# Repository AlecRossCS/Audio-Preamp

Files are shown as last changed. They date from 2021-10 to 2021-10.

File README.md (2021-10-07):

# Audio-Preamp
This is an analog audio preamplifier, designed on first principles as well as help from Small Signal Audio Design by Douglas Self, as well as applications notes from Rod Elliott. 

## Schematic
the schematic is listed in the project files, in many parts. [the pdf schematic is linked here](Audio_Preamp.pdf)

## Power Supply Design
The design for the power supply relies on an Input AC plug pack, anywhere between 12-25V input.
power supply_schematic
it is designed with some input protection from transient spikes of wall voltage, if the plug pack is poorly designed by a MOV. Effectively it is a half wave rectifier for each rail, and a virtual ground point.  Otherwise it is a fairly standard linear power supply, except that to reduce cost and part count, a input capacitance is obtained through a capacitance multiplier. the only disadvantage is that it cannot help source higher currents, but that is not needed on a preamplifier as well as being mitigated by a high output capacitance. 

## Other Design elements

The rest of the design is fairly lengthy, and involves several larger elements taken from basic principles. The input is a standard RCA audio jack, as it is an easier connection and has better noise characteristics than a balanced input. the controls follow with a baxendall tonal control, and then a baxendall volume control. All of this is designed to be very low noise (-90DB) and high fidelity all analog preamp. 

## Hardware layout

This board needed to be relatively space efficient, and total space is one factor which influences cost of production. so this is designed as a 50x80 mm  4 layer board, which should make a favorable production cost. as this is fiarly small and lower power another cost saver is it only needs 1 oz copper, not 2 oz copper. Another point for production is that almost all components are SMD, thus decreases cost of assembly. 

overall mockup:
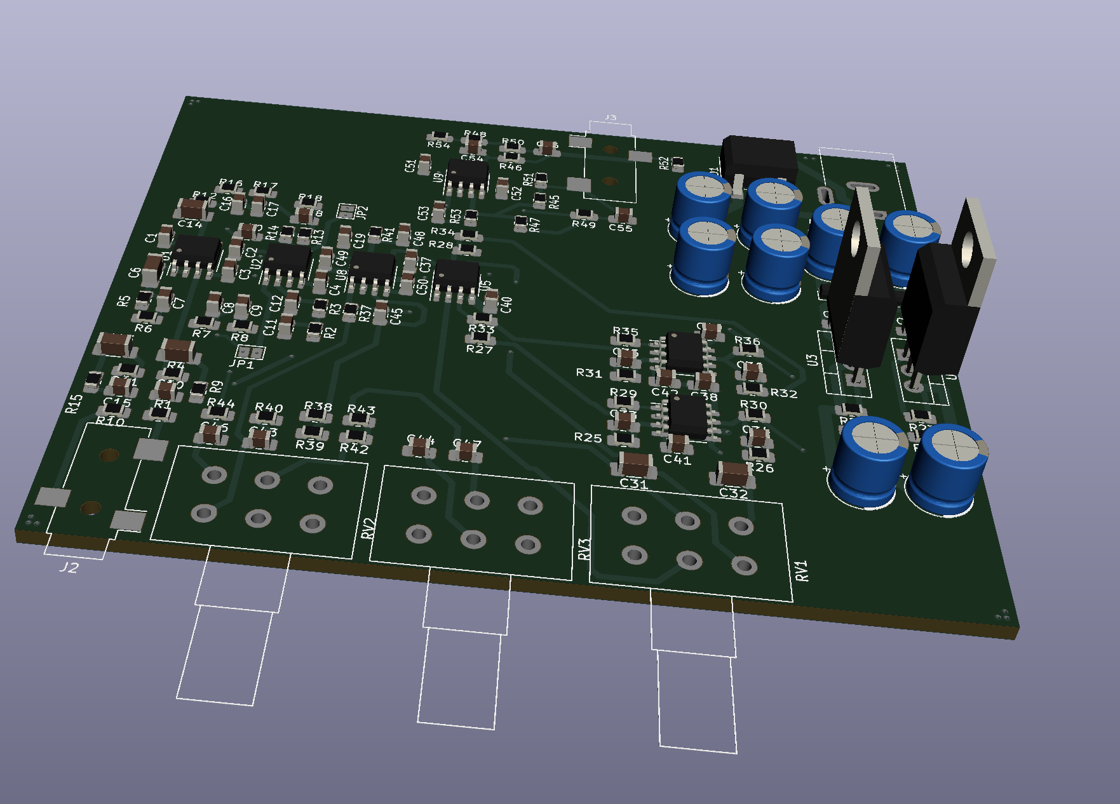
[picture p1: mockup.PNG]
model


## version 2
This version has RCA out, but V2 may have balanced output as well as active crossovers.

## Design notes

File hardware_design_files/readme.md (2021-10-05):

# Hardware Design File Section
all schematics created using Kicad

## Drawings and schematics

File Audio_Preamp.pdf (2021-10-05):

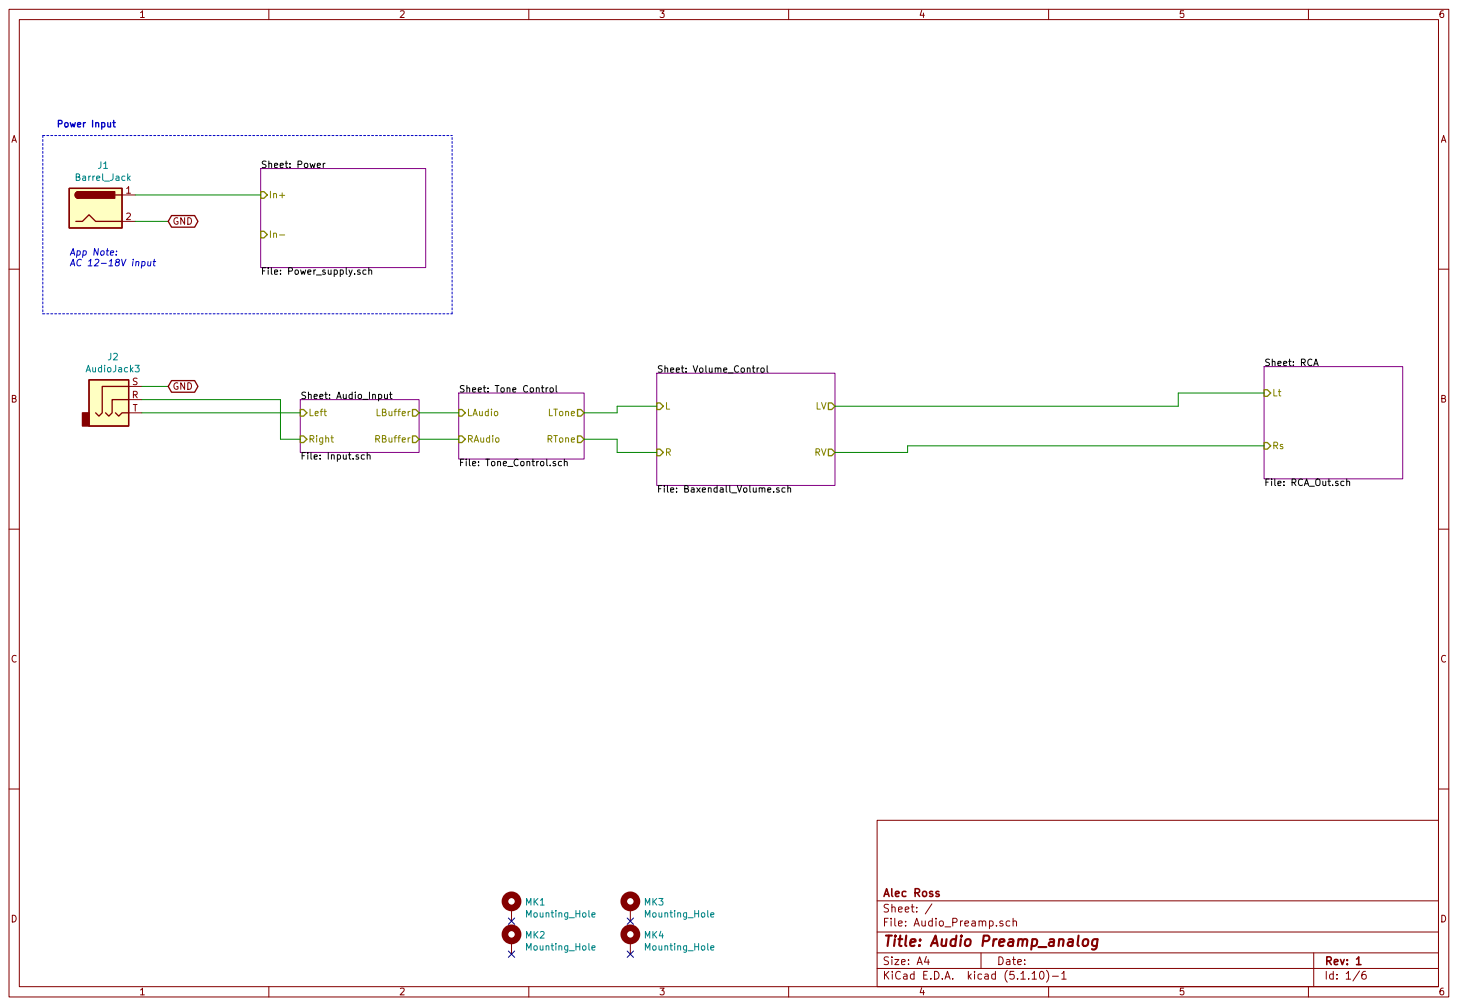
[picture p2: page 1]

Sheet: Power File: Power_supply.sch

Lt Rs Sheet: Tone Control File: Tone_Control.sch

File: Audio_Preamp.sch Sheet: / Alec Ross

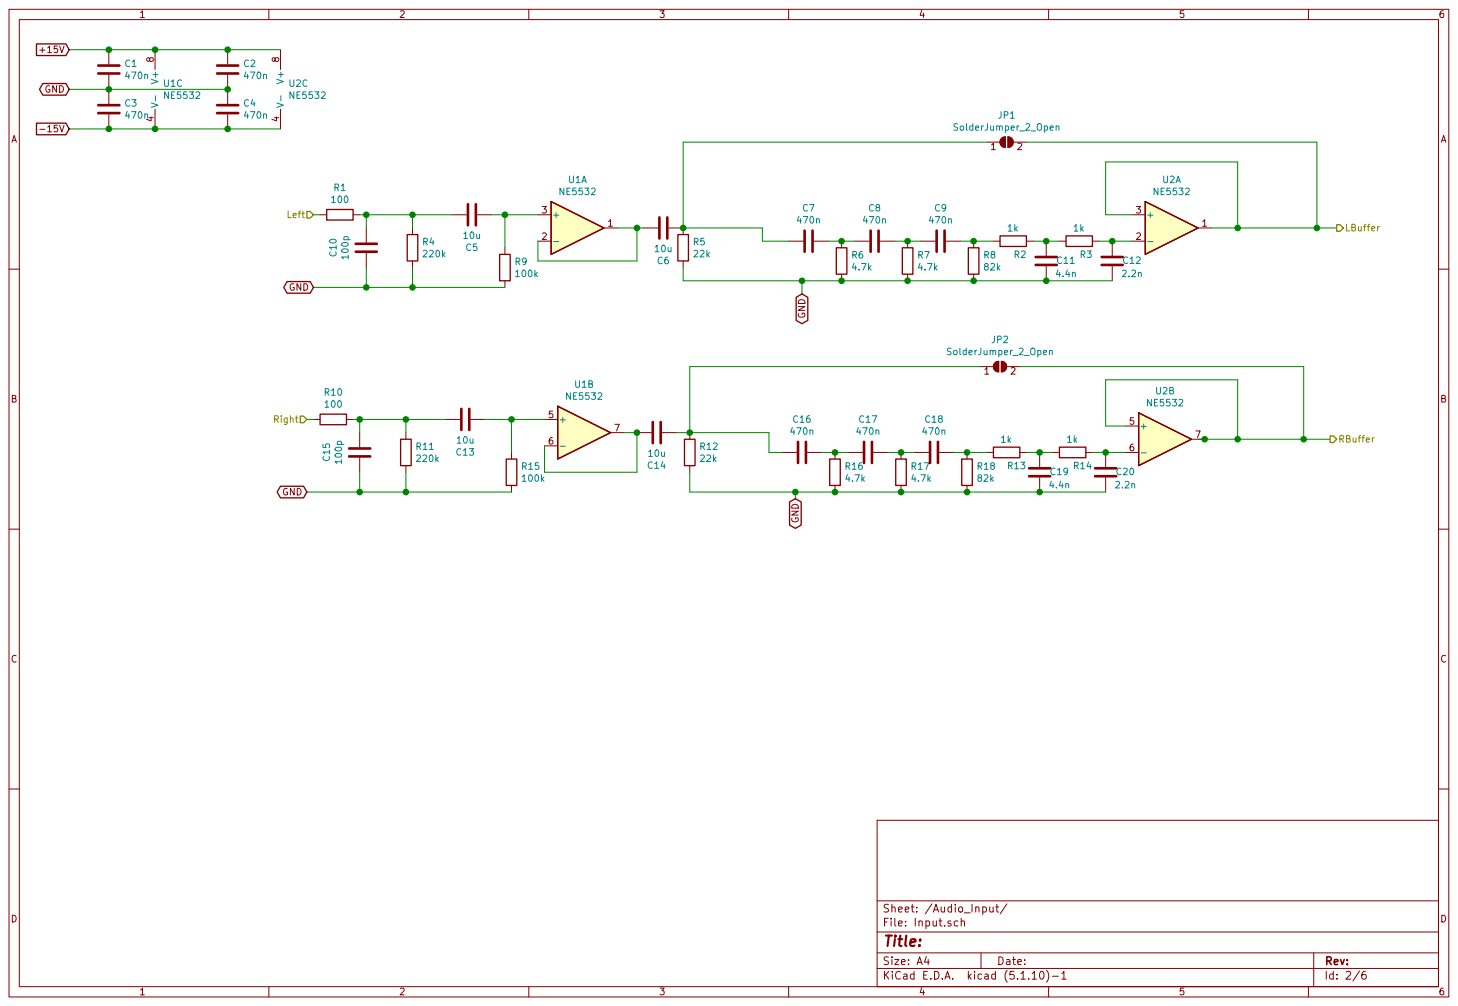
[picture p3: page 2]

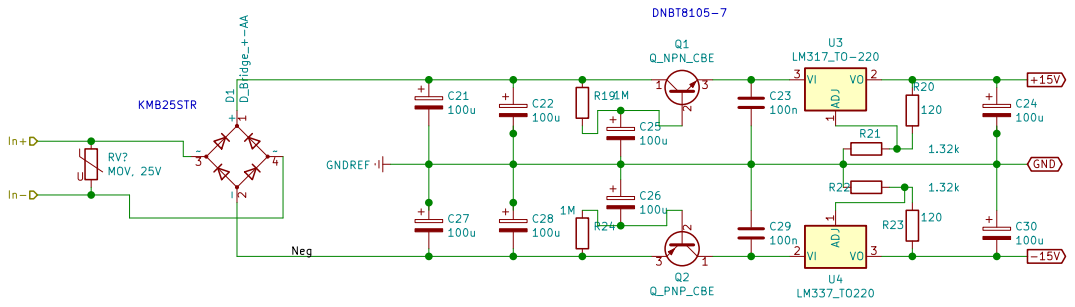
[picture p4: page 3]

File: Power_supply.sch Sheet: /Power/
Id: 3/6 Title:

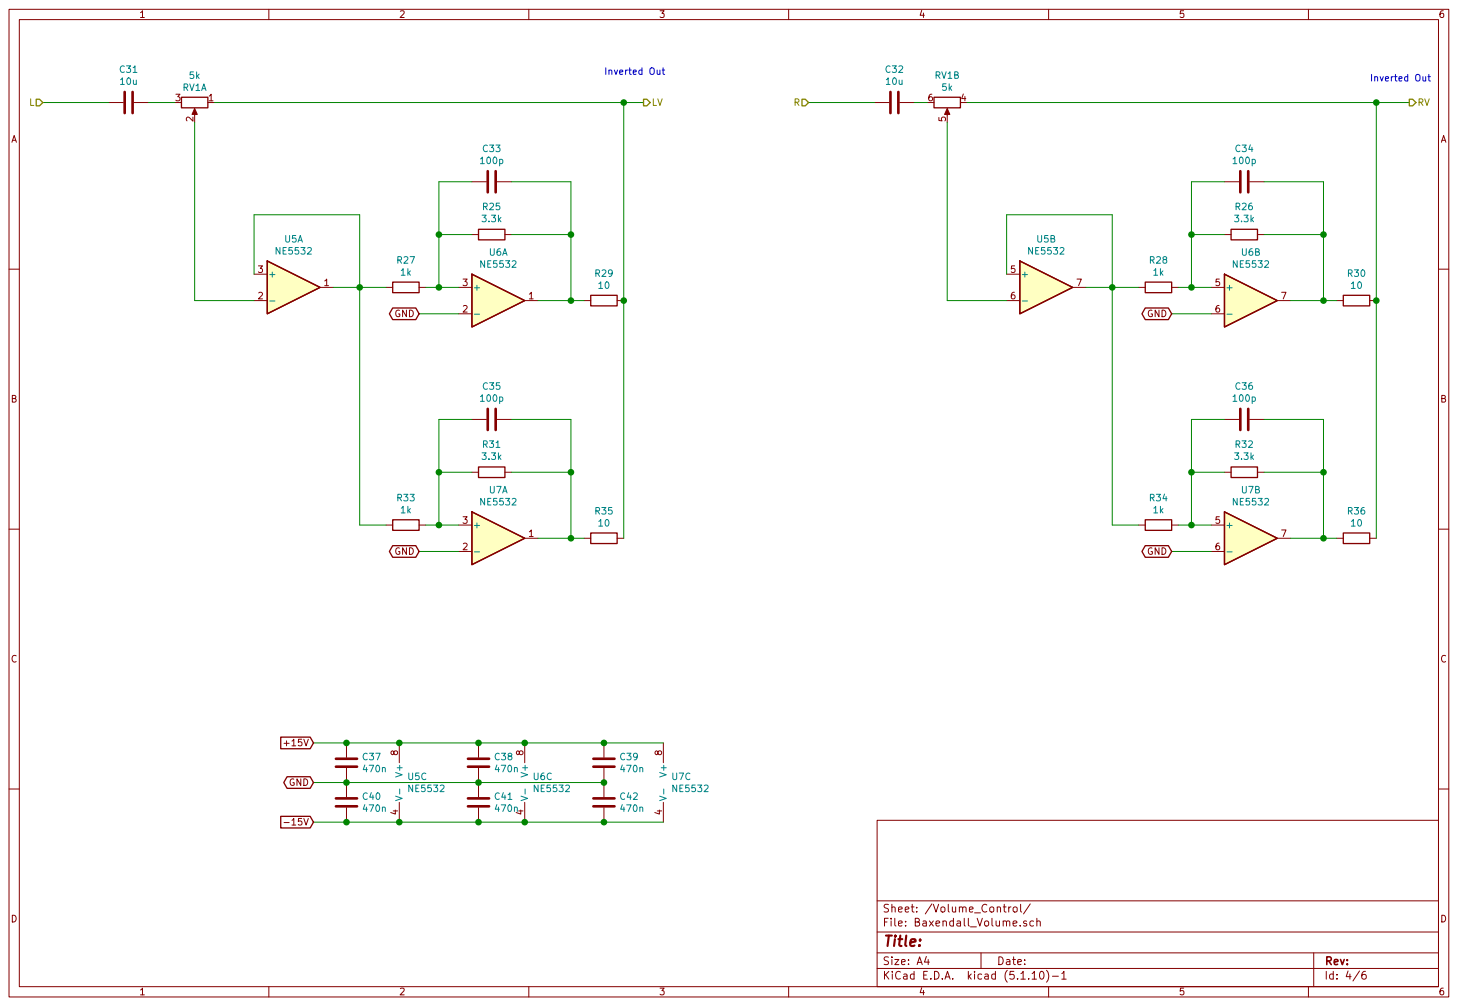
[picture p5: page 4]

Inverted Out

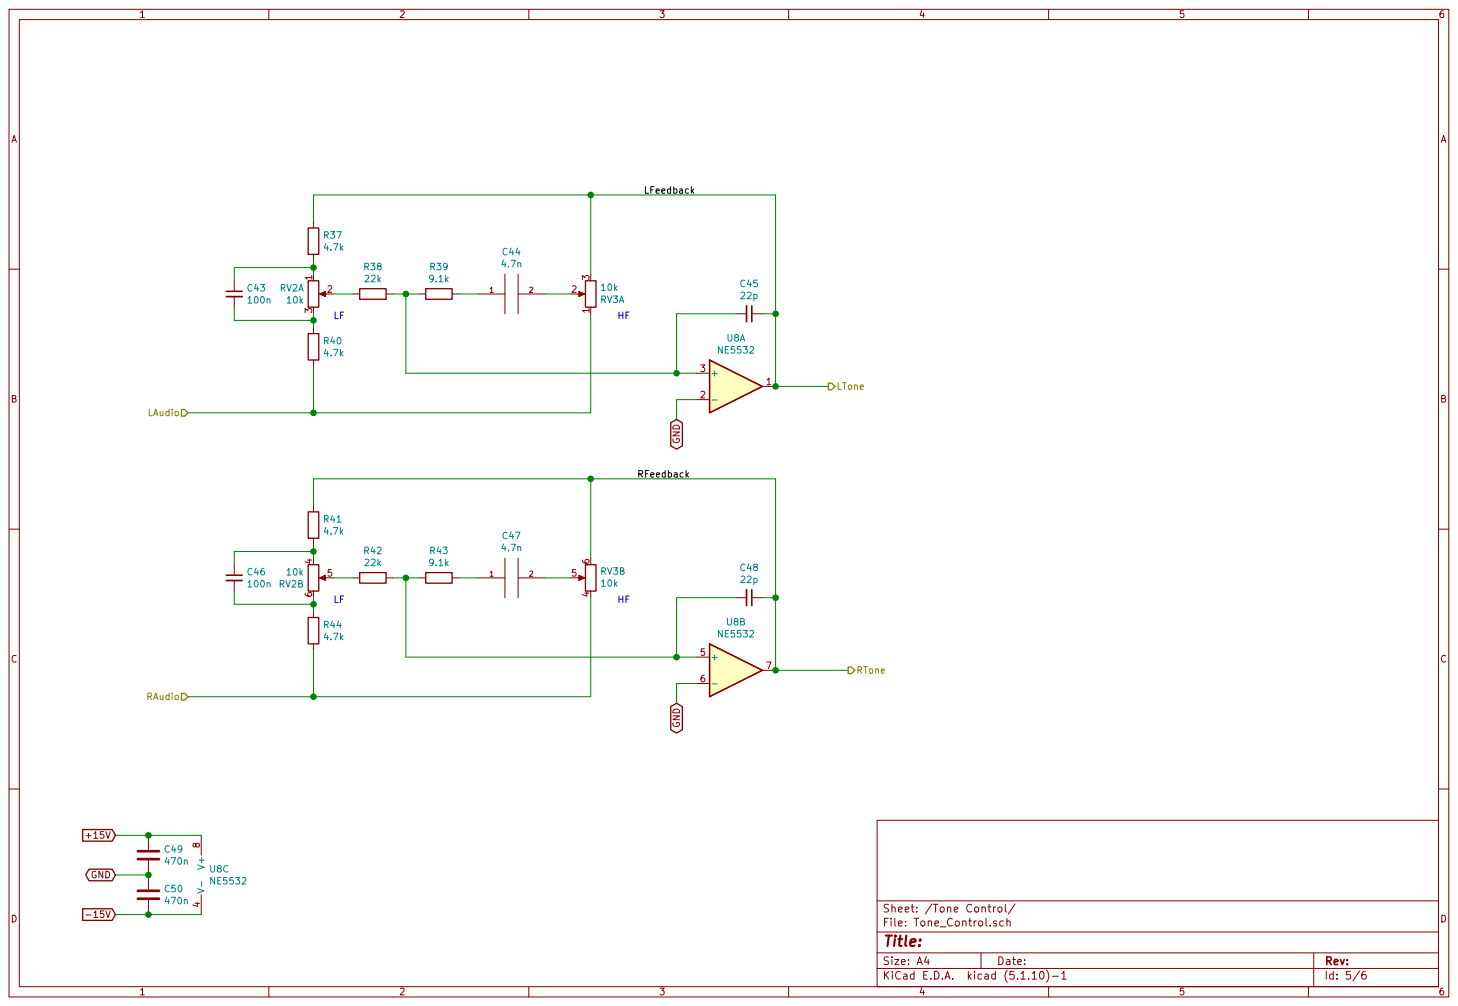
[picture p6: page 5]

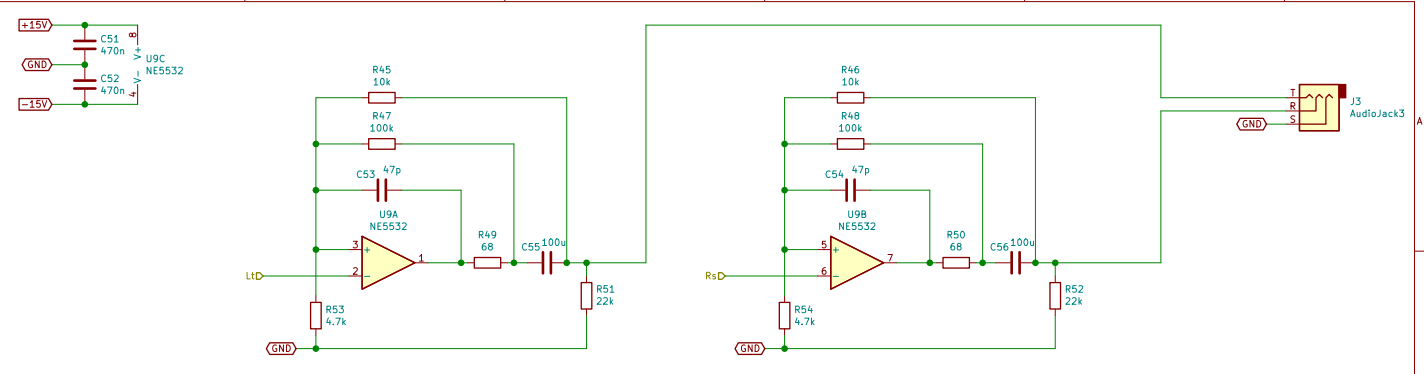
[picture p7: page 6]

File: RCA_Out.sch Sheet: /RCA/
Id: 6/6 Title:

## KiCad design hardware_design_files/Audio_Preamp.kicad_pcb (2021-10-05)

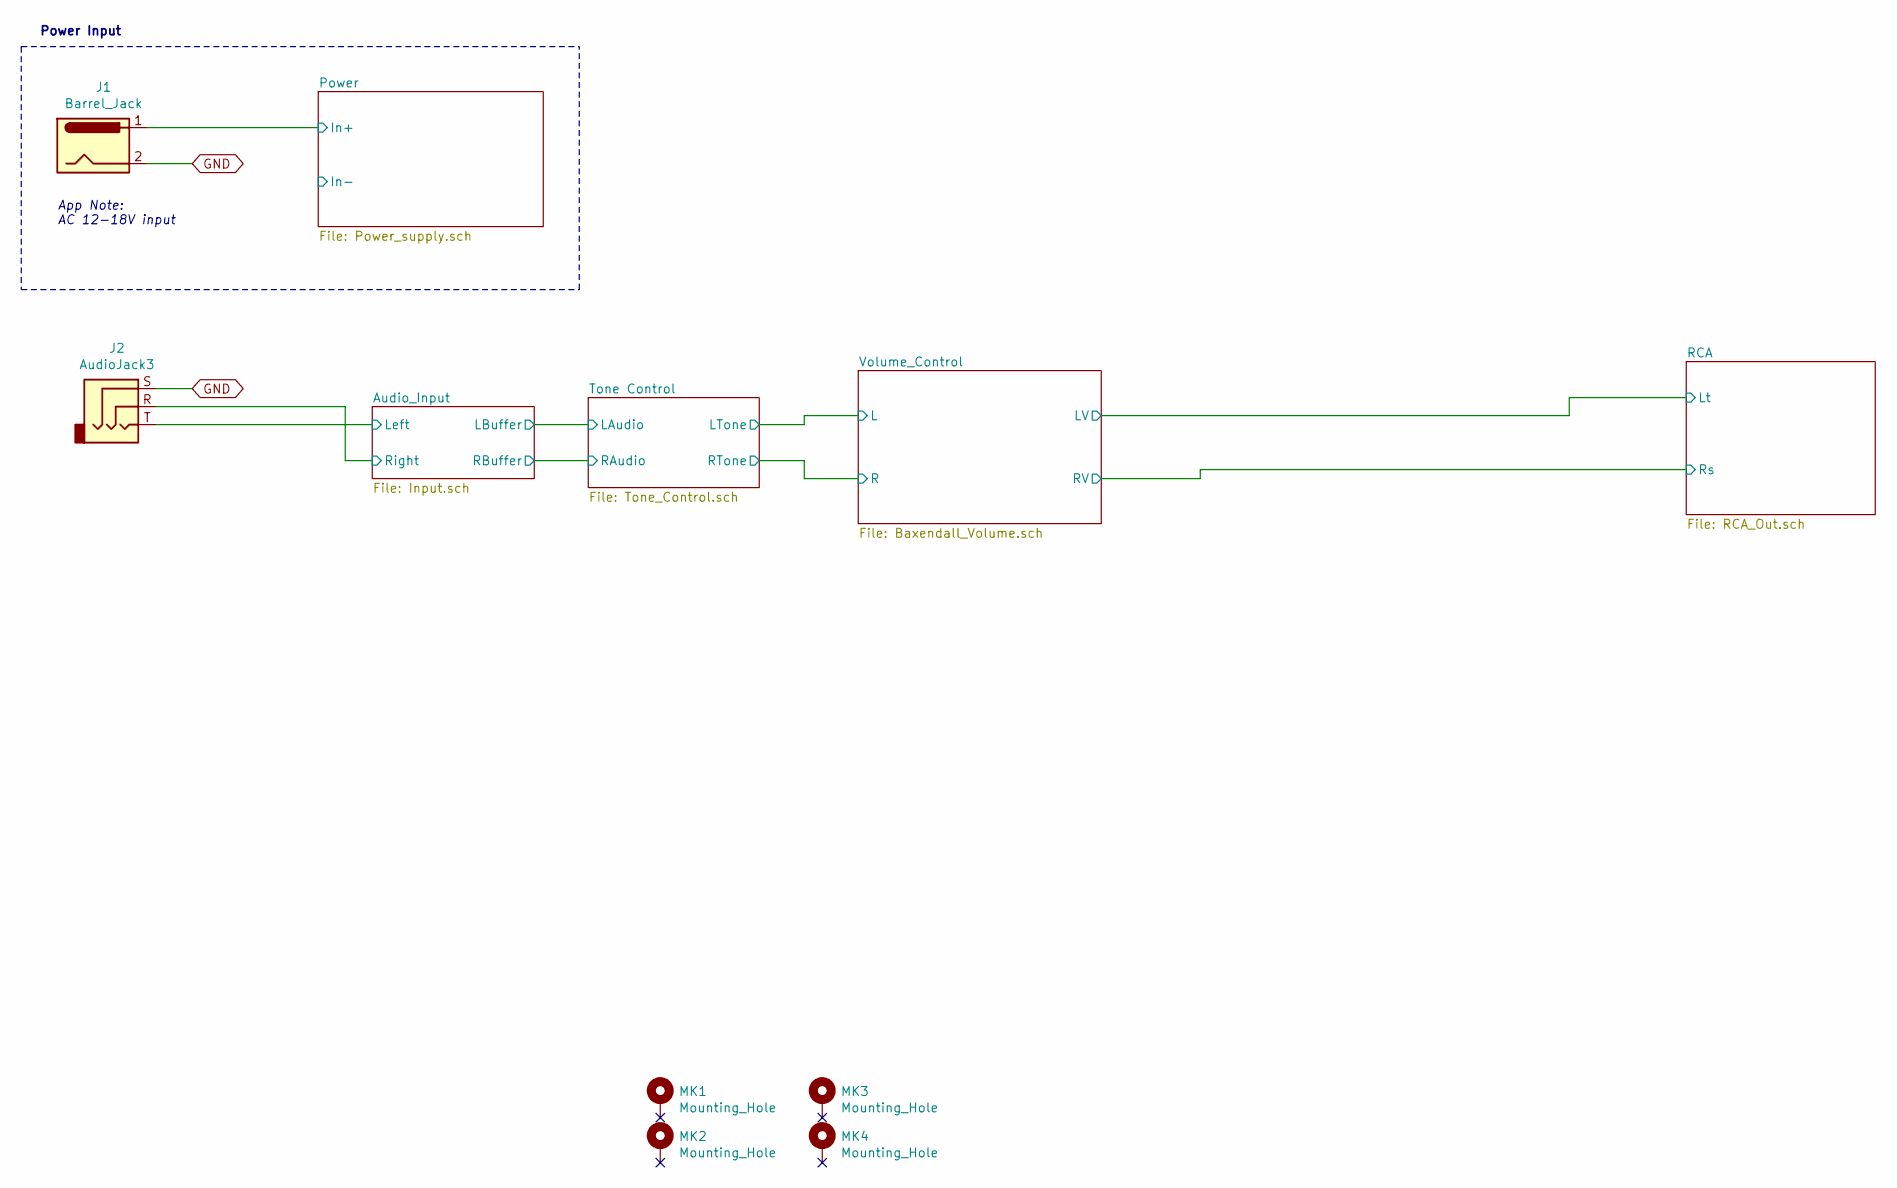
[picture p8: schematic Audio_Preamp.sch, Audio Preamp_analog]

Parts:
J1: Barrel_Jack; BarrelJack_Wuerth_6941xx301002
J2: AudioJack3; Jack_3.5mm_CUI_SJ-3523-SMT_Horizontal
MK1, MK2, MK3, MK4: Mounting_Hole; MountingHole_3.2mm_M3_ISO7380

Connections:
/Audio_Input/Left: J2.T; also elsewhere on the board
/Audio_Input/Right: J2.R; also elsewhere on the board
/Power/In+: J1.1; also elsewhere on the board
GND: J1.2, J2.S; also elsewhere on the board

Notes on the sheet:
Power Input
App Note: AC 12-18V input

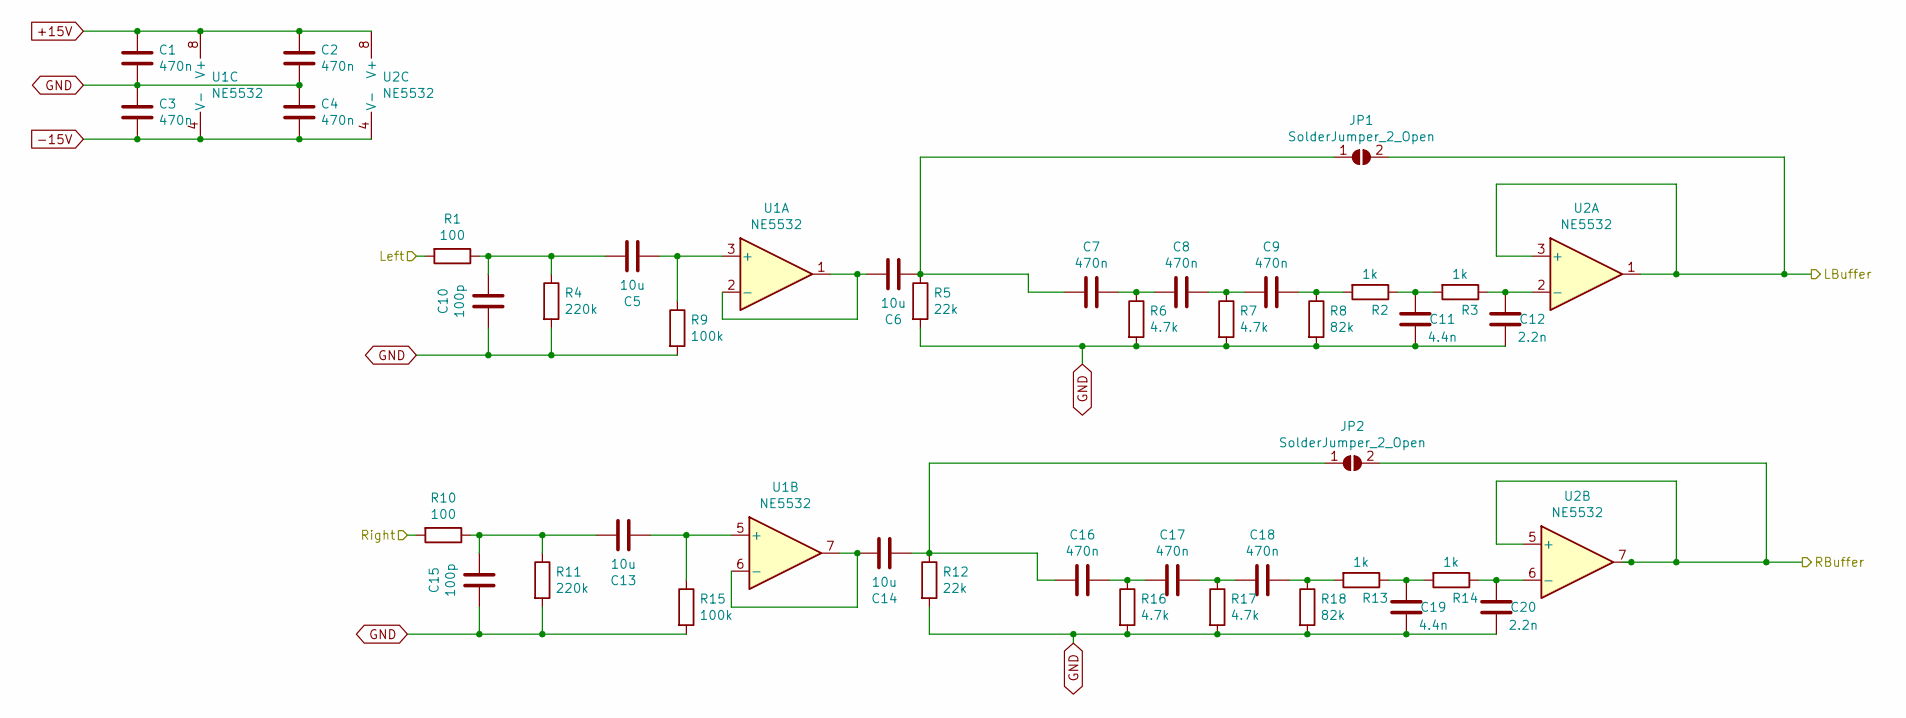
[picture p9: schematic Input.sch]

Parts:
C1, C2, C3, C4, C7, C8, C9, C16, C17, C18: 470n; C_0805_2012Metric_Pad1.18x1.45mm_HandSolder
C5, C6, C13, C14: 10u; C_1206_3216Metric_Pad1.33x1.80mm_HandSolder
C10, C15: 100p; C_0805_2012Metric_Pad1.18x1.45mm_HandSolder
C11, C19: 4.4n; C_0805_2012Metric_Pad1.18x1.45mm_HandSolder
C12, C20: 2.2n; C_0805_2012Metric_Pad1.18x1.45mm_HandSolder
JP1, JP2: SolderJumper_2_Open; SolderJumper-2_P1.3mm_Open_Pad1.0x1.5mm
R1, R10: 100; R_0805_2012Metric_Pad1.20x1.40mm_HandSolder
R2, R3, R13, R14: 1k; R_0805_2012Metric_Pad1.20x1.40mm_HandSolder
R4, R11: 220k; R_0805_2012Metric_Pad1.20x1.40mm_HandSolder
R5, R12: 22k; R_0805_2012Metric_Pad1.20x1.40mm_HandSolder
R6, R7, R16, R17: 4.7k; R_0805_2012Metric_Pad1.20x1.40mm_HandSolder
R8, R18: 82k; R_0805_2012Metric_Pad1.20x1.40mm_HandSolder
R9, R15: 100k; R_0805_2012Metric_Pad1.20x1.40mm_HandSolder
U1, U2: NE5532; SOIC-8_3.9x4.9mm_P1.27mm

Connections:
+15V: C1.1, C2.1, U1.8 (V+), U2.8 (V+); also elsewhere on the board
-15V: C3.2, C4.2, U1.4 (V-), U2.4 (V-); also elsewhere on the board
/Audio_Input/Left: R1.2; also elsewhere on the board
/Audio_Input/Right: R10.2; also elsewhere on the board
/Tone Control/LAudio: JP1.2 (B), U2.1, U2.3 (+); also elsewhere on the board
/Tone Control/RAudio: JP2.2 (B), U2.5 (+), U2.7; also elsewhere on the board
GND: C1.2, C2.2, C3.1, C4.1, C10.2, C11.1, C12.1, C15.2, C19.1, C20.1, R4.2, R5.2, R6.2, R7.2, R8.2, R9.2, R11.2, R12.2, R15.2, R16.2, R17.2, R18.2; also elsewhere on the board
unnamed: C5.2, R9.1, U1.3 (+)
unnamed: C6.1, U1.1, U1.2 (-)
unnamed: C6.2, C7.2, JP1.1 (A), R5.1
unnamed: C7.1, C8.2, R6.1
unnamed: C8.1, C9.2, R7.1
unnamed: C9.1, R2.2, R8.1
unnamed: C5.1, C10.1, R1.1, R4.1
unnamed: C11.2, R2.1, R3.2
unnamed: C12.2, R3.1, U2.2 (-)
unnamed: C13.1, C15.1, R10.1, R11.1
unnamed: C13.2, R15.1, U1.5 (+)
unnamed: C14.1, U1.6 (-), U1.7
unnamed: C14.2, C16.2, JP2.1 (A), R12.1
unnamed: C16.1, C17.2, R16.1
unnamed: C17.1, C18.2, R17.1
unnamed: C18.1, R13.2, R18.1
unnamed: C19.2, R13.1, R14.2
unnamed: C20.2, R14.1, U2.6 (-)

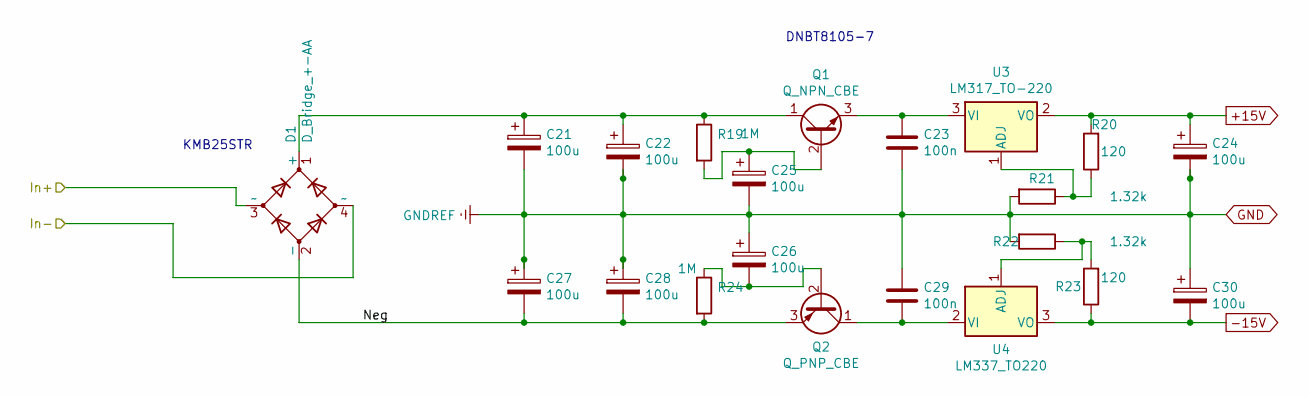
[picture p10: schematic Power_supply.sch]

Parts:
C21, C22, C24, C25, C26, C27, C28, C30: 100u; CP_Radial_D6.3mm_P2.50mm
C23, C29: 100n; C_0805_2012Metric_Pad1.18x1.45mm_HandSolder
D1: D_Bridge_+-AA; Diode_Bridge_Vishay_DFS
Q1: Q_NPN_CBE; SOT-23
Q2: Q_PNP_CBE; SOT-23
R19, R24: 1M; R_0805_2012Metric_Pad1.20x1.40mm_HandSolder
R20, R23: 120; R_0805_2012Metric_Pad1.20x1.40mm_HandSolder
R21, R22: 1.32k; R_0805_2012Metric_Pad1.20x1.40mm_HandSolder
U3: LM317_TO-220; TO-220-3_Vertical
U4: LM337_TO220; TO-220-3_Vertical

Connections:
+15V: C24.1, R20.2, U3.2 (VO); also elsewhere on the board
-15V: C30.2, R23.1, U4.3 (VO); also elsewhere on the board
/Power/In+: D1.3 (~~); also elsewhere on the board
/Power/In-: D1.4 (~~)
/Power/Neg: C27.2, C28.2, D1.2 (-), Q2.3 (E), R24.2
GND: C21.2, C22.2, C23.2, C24.2, C25.2, C26.1, C27.1, C28.1, C29.1, C30.1, R21.2, R22.2; also elsewhere on the board
unnamed: C21.1, C22.1, D1.1 (+), Q1.1 (C), R19.1
unnamed: C23.1, Q1.3 (E), U3.3 (VI)
unnamed: C25.1, Q1.2 (B), R19.2
unnamed: C26.2, Q2.2 (B), R24.1
unnamed: C29.2, Q2.1 (C), U4.2 (VI)
unnamed: R20.1, R21.1, U3.1 (ADJ)
unnamed: R22.1, R23.2, U4.1 (ADJ)

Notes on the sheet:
DNBT8105-7
KMB25STR

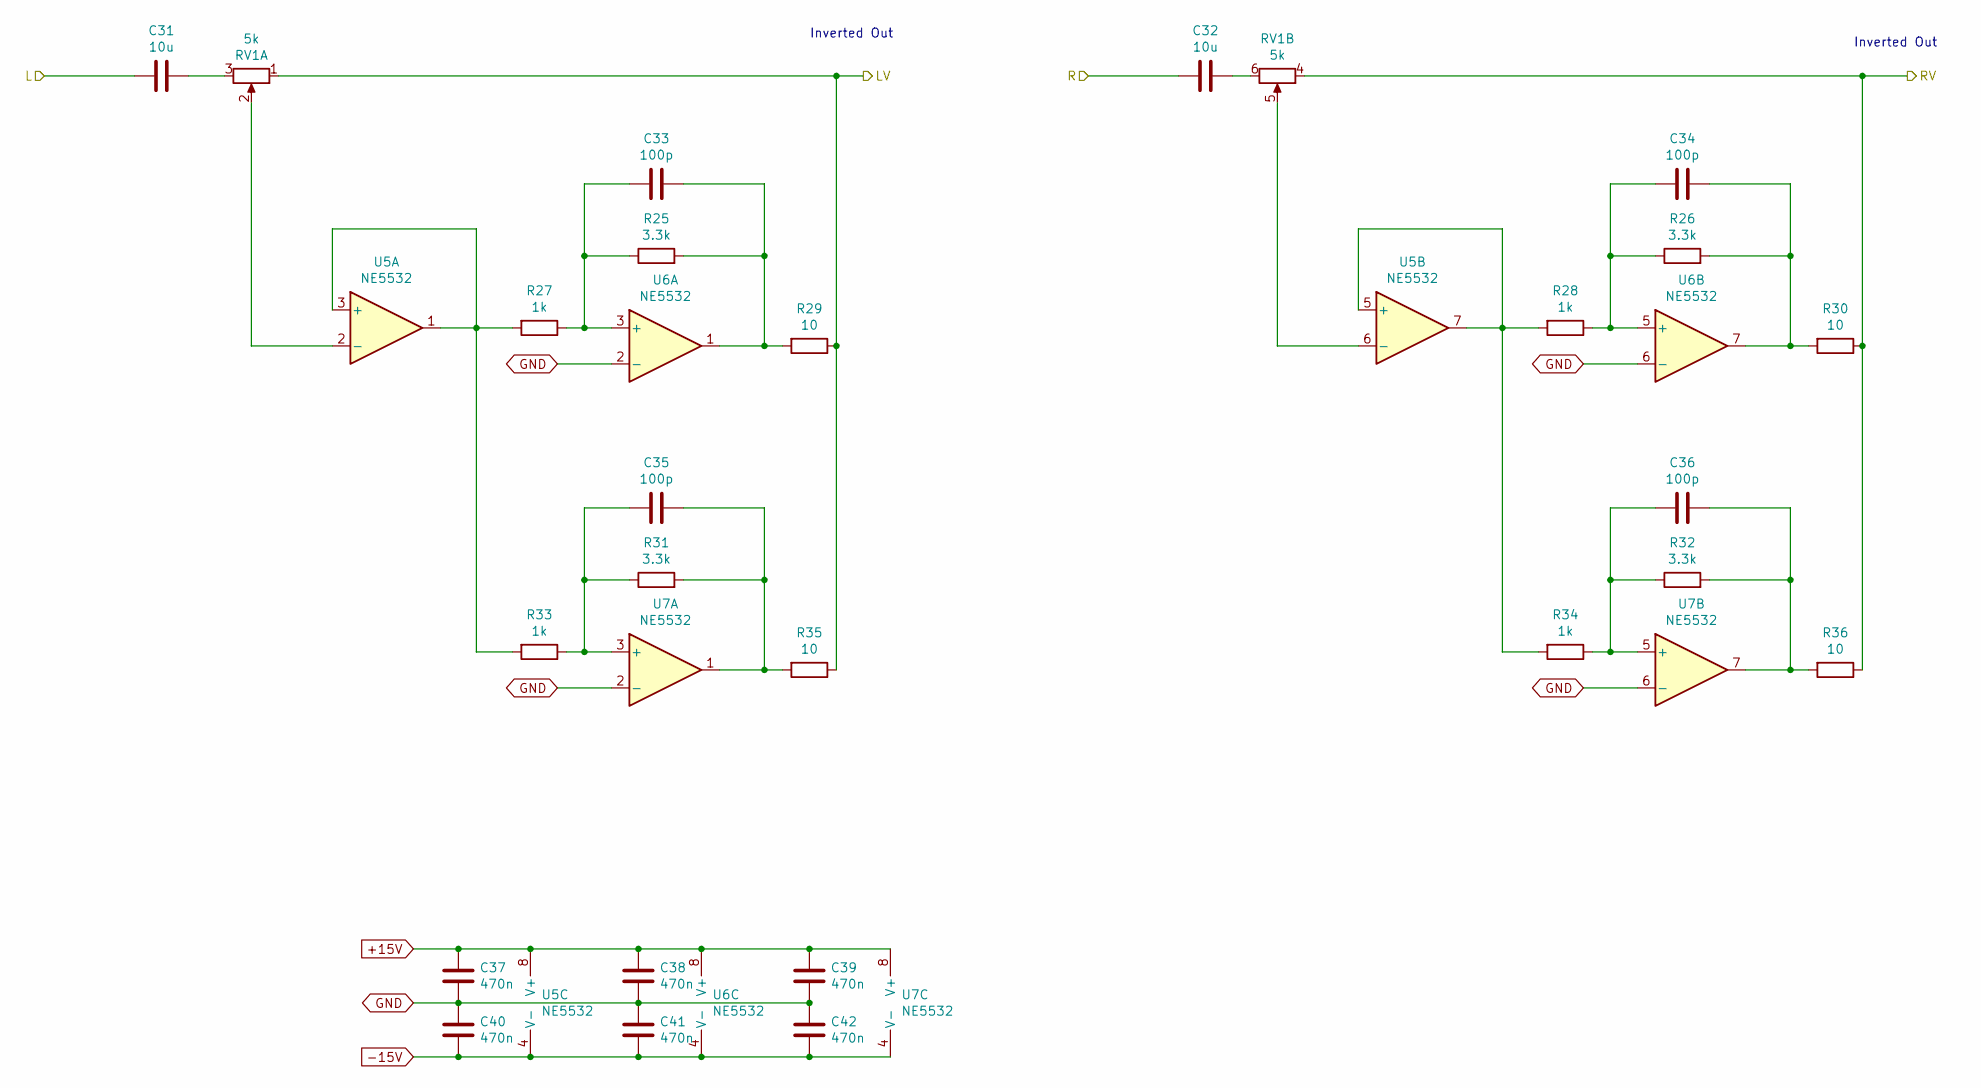
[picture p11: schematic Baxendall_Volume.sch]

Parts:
C31, C32: 10u; C_1206_3216Metric_Pad1.33x1.80mm_HandSolder
C33, C34, C35, C36: 100p; C_0805_2012Metric_Pad1.18x1.45mm_HandSolder
C37, C38, C39, C40, C41, C42: 470n; C_0805_2012Metric_Pad1.18x1.45mm_HandSolder
R25, R26, R31, R32: 3.3k; R_0805_2012Metric_Pad1.20x1.40mm_HandSolder
R27, R28, R33, R34: 1k; R_0805_2012Metric_Pad1.20x1.40mm_HandSolder
R29, R30, R35, R36: 10; R_0805_2012Metric_Pad1.20x1.40mm_HandSolder
RV1: 5k; Potentiometer_Alps_RK163_Dual_Horizontal
U5, U6, U7: NE5532; SOIC-8_3.9x4.9mm_P1.27mm

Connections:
+15V: C37.1, C38.1, C39.1, U5.8 (V+), U6.8 (V+), U7.8 (V+); also elsewhere on the board
-15V: C40.2, C41.2, C42.2, U5.4 (V-), U6.4 (V-), U7.4 (V-); also elsewhere on the board
/Volume_Control/L: C31.2; also elsewhere on the board
/Volume_Control/LV: R29.1, R35.1, RV1.1; also elsewhere on the board
/Volume_Control/R: C32.2; also elsewhere on the board
/Volume_Control/RV: R30.1, R36.1, RV1.4; also elsewhere on the board
GND: C37.2, C38.2, C39.2, C40.1, C41.1, C42.1, U6.2 (-), U6.6 (-), U7.2 (-), U7.6 (-); also elsewhere on the board
unnamed: C31.1, RV1.3
unnamed: C32.1, RV1.6
unnamed: C33.1, R25.2, R29.2, U6.1
unnamed: C33.2, R25.1, R27.1, U6.3 (+)
unnamed: C34.1, R26.2, R30.2, U6.7
unnamed: C34.2, R26.1, R28.1, U6.5 (+)
unnamed: C35.1, R31.2, R35.2, U7.1
unnamed: C35.2, R31.1, R33.1, U7.3 (+)
unnamed: C36.1, R32.2, R36.2, U7.7
unnamed: C36.2, R32.1, R34.1, U7.5 (+)
unnamed: R27.2, R33.2, U5.1, U5.3 (+)
unnamed: R28.2, R34.2, U5.5 (+), U5.7
unnamed: RV1.2, U5.2 (-)
unnamed: RV1.5, U5.6 (-)

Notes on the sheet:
Inverted Out

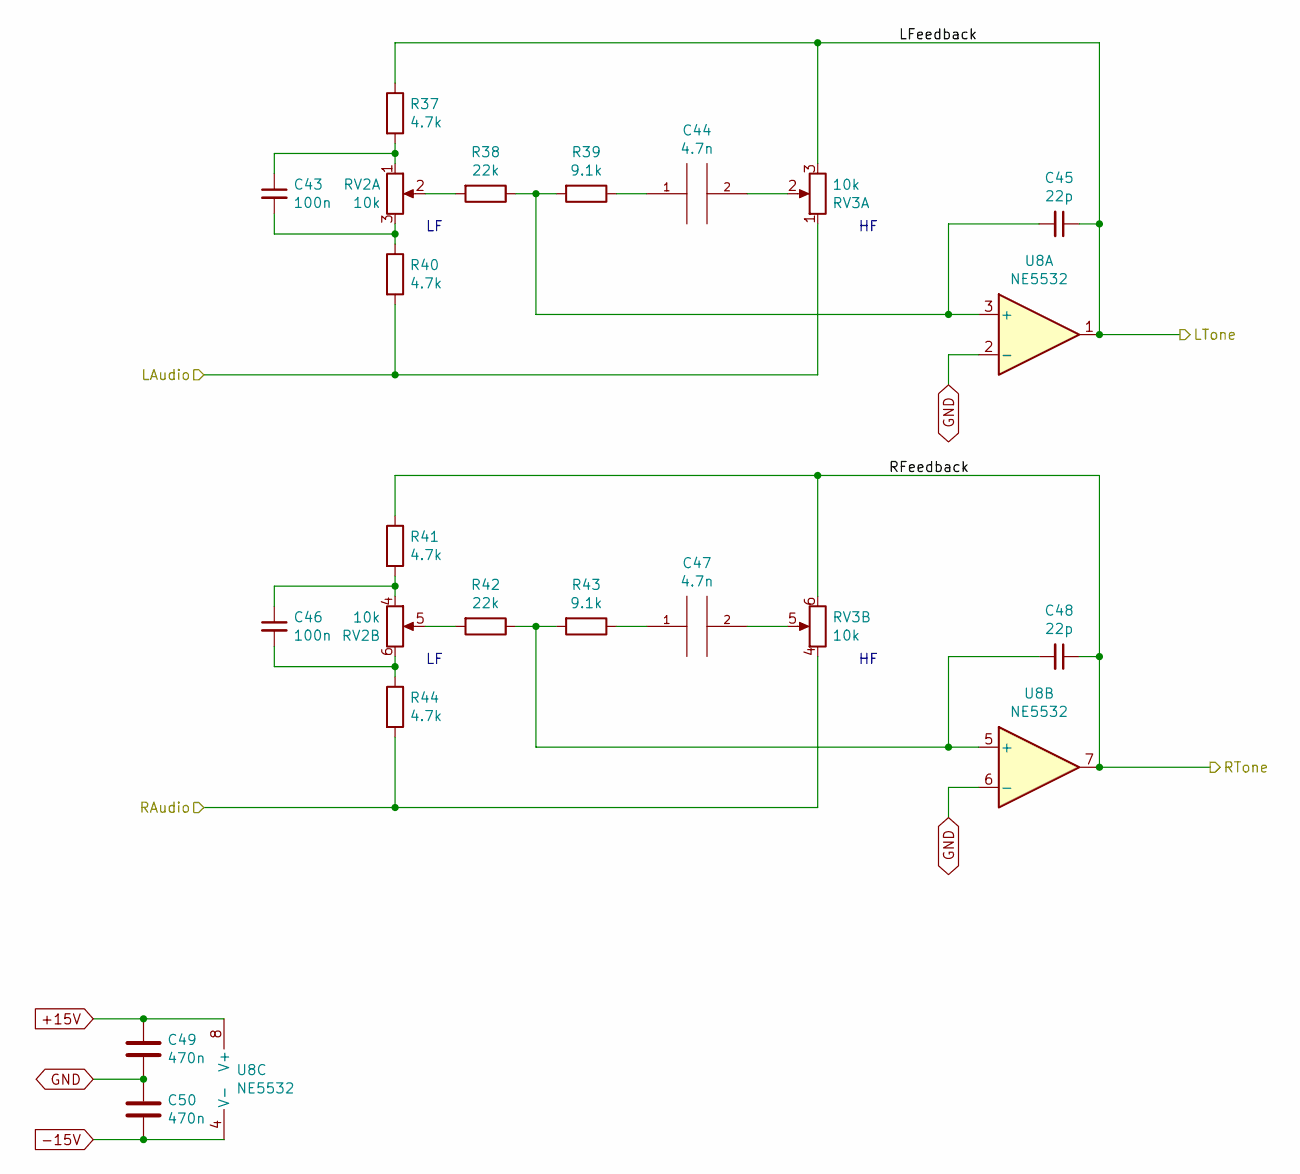
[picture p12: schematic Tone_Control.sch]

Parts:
C43, C46: 100n; C_0805_2012Metric_Pad1.18x1.45mm_HandSolder
C44, C47: 4.7n; C_0805_2012Metric_Pad1.18x1.45mm_HandSolder
C45, C48: 22p; C_0805_2012Metric_Pad1.18x1.45mm_HandSolder
C49, C50: 470n; C_0805_2012Metric_Pad1.18x1.45mm_HandSolder
R37, R40, R41, R44: 4.7k; R_0805_2012Metric_Pad1.20x1.40mm_HandSolder
R38, R42: 22k; R_0805_2012Metric_Pad1.20x1.40mm_HandSolder
R39, R43: 9.1k; R_0805_2012Metric_Pad1.20x1.40mm_HandSolder
RV2, RV3: 10k; Potentiometer_Alps_RK163_Dual_Horizontal
U8: NE5532; SOIC-8_3.9x4.9mm_P1.27mm

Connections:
+15V: C49.1, U8.8 (V+); also elsewhere on the board
-15V: C50.2, U8.4 (V-); also elsewhere on the board
/Tone Control/LAudio: R40.2, RV3.1; also elsewhere on the board
/Tone Control/RAudio: R44.2, RV3.4; also elsewhere on the board
/Volume_Control/L: C45.1, R37.1, RV3.3, U8.1; also elsewhere on the board
/Volume_Control/R: C48.1, R41.1, RV3.6, U8.7; also elsewhere on the board
GND: C49.2, C50.1, U8.2 (-), U8.6 (-); also elsewhere on the board
unnamed: C43.1, R37.2, RV2.1
unnamed: C43.2, R40.1, RV2.3
unnamed: C44.1, R39.1
unnamed: C44.2, RV3.2
unnamed: C45.2, R38.1, R39.2, U8.3 (+)
unnamed: C46.1, R41.2, RV2.4
unnamed: C46.2, R44.1, RV2.6
unnamed: C47.1, R43.1
unnamed: C47.2, RV3.5
unnamed: C48.2, R42.1, R43.2, U8.5 (+)
unnamed: R38.2, RV2.2
unnamed: R42.2, RV2.5

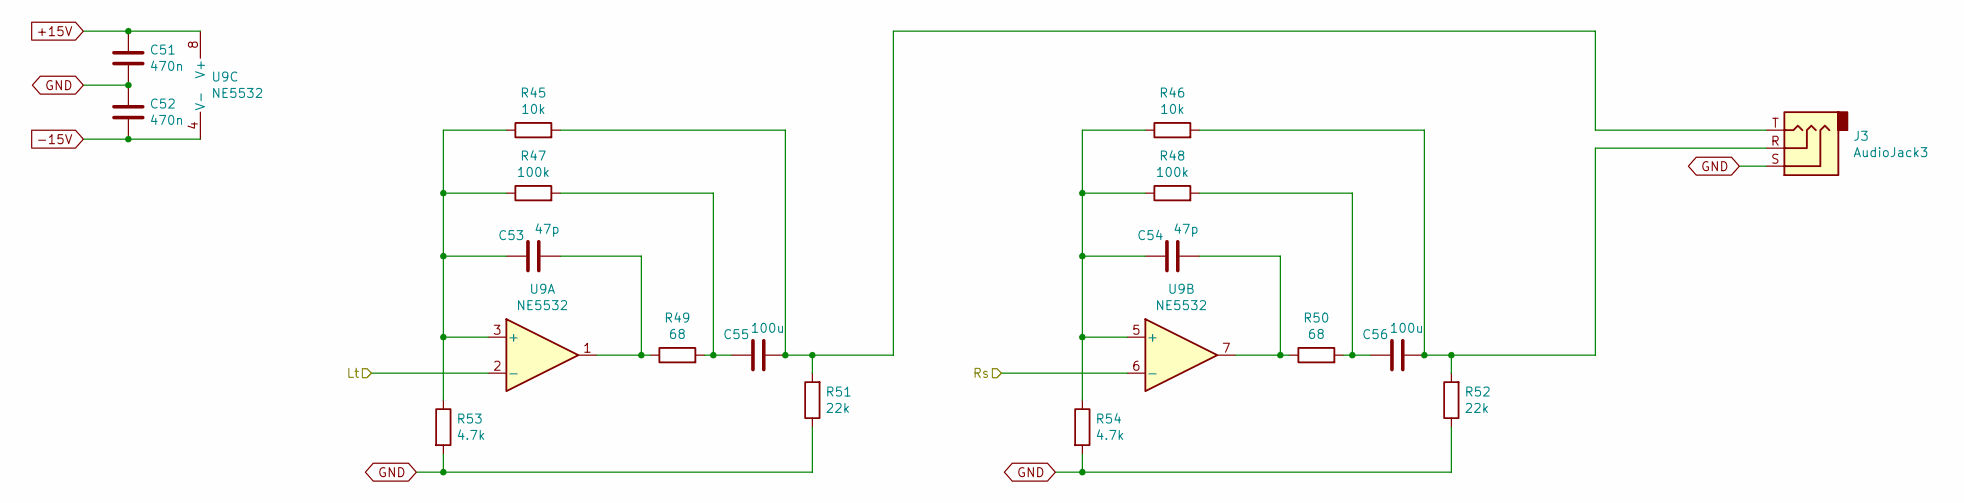
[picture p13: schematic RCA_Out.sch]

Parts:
C51, C52: 470n; C_0805_2012Metric_Pad1.18x1.45mm_HandSolder
C53, C54: 47p; C_0805_2012Metric_Pad1.18x1.45mm_HandSolder
C55, C56: 100u; C_0805_2012Metric_Pad1.18x1.45mm_HandSolder
J3: AudioJack3; Jack_3.5mm_CUI_SJ-3523-SMT_Horizontal
R45, R46: 10k; R_0805_2012Metric_Pad1.20x1.40mm_HandSolder
R47, R48: 100k; R_0805_2012Metric_Pad1.20x1.40mm_HandSolder
R49, R50: 68; R_0805_2012Metric_Pad1.20x1.40mm_HandSolder
R51, R52: 22k; R_0805_2012Metric_Pad1.20x1.40mm_HandSolder
R53, R54: 4.7k; R_0805_2012Metric_Pad1.20x1.40mm_HandSolder
U9: NE5532

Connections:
+15V: C51.1, U9.8 (V+); also elsewhere on the board
-15V: C52.2, U9.4 (V-); also elsewhere on the board
/Volume_Control/LV: U9.2 (-); also elsewhere on the board
/Volume_Control/RV: U9.6 (-); also elsewhere on the board
GND: C51.2, C52.1, J3.S, R51.1, R52.1, R53.2, R54.2; also elsewhere on the board
unnamed: C53.1, R45.1, R47.1, R53.1, U9.3 (+)
unnamed: C53.2, R49.1, U9.1
unnamed: C54.1, R46.1, R48.1, R54.1, U9.5 (+)
unnamed: C54.2, R50.1, U9.7
unnamed: C55.1, R47.2, R49.2
unnamed: C55.2, J3.T, R45.2, R51.2
unnamed: C56.1, R48.2, R50.2
unnamed: C56.2, J3.R, R46.2, R52.2

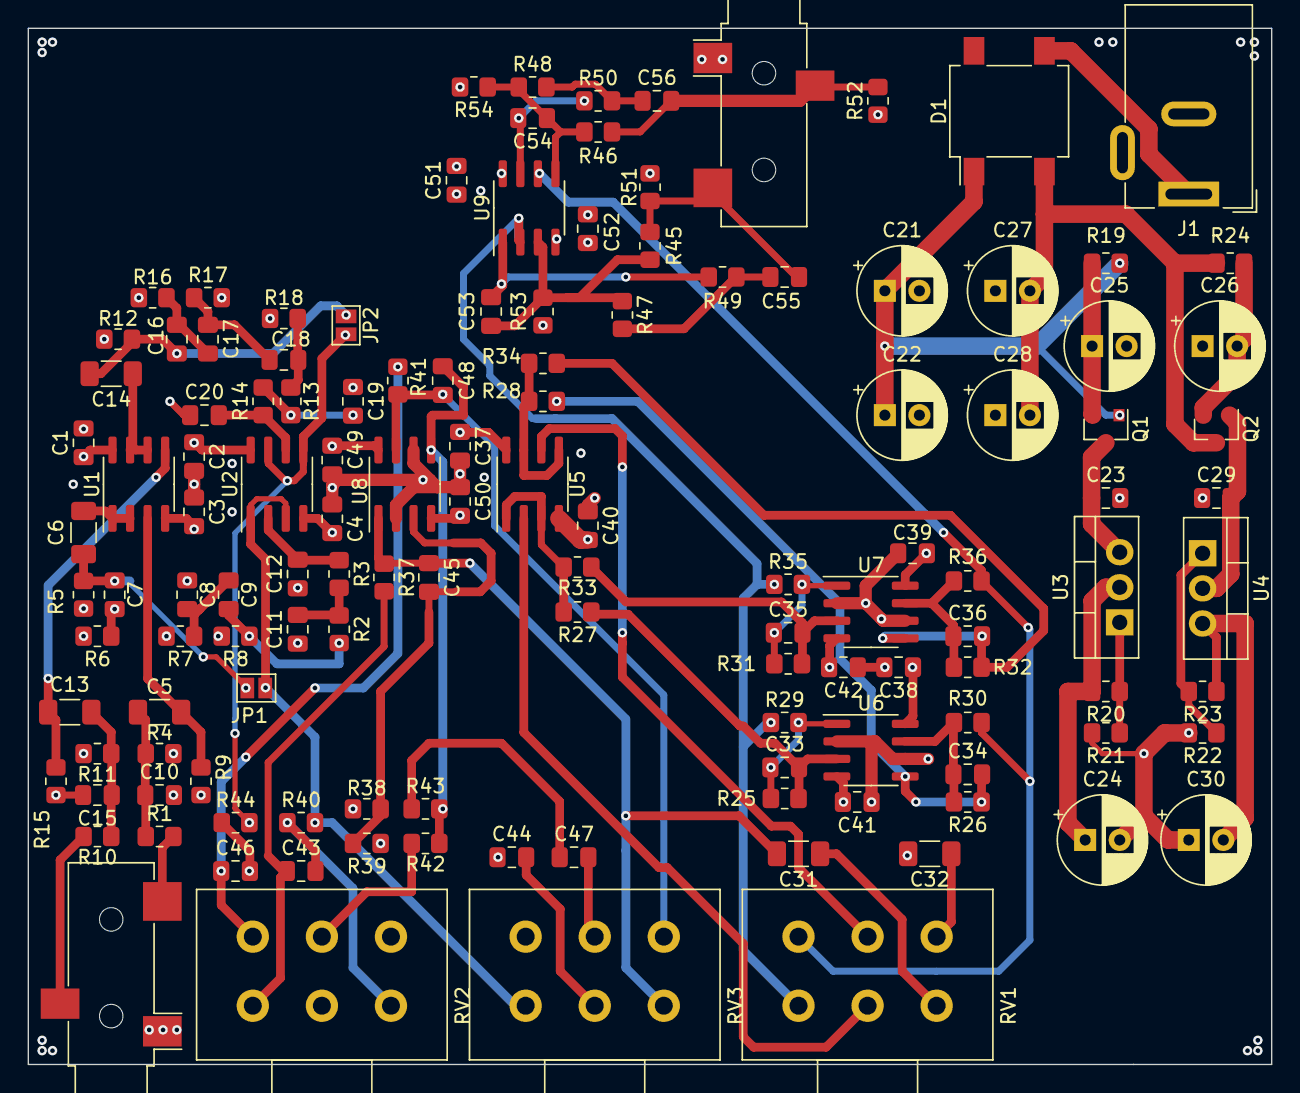
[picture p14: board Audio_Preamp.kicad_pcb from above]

Board: 4 copper layers, 90.0 x 75.0 mm, 130 parts (0 on the bottom side), 72 nets.
